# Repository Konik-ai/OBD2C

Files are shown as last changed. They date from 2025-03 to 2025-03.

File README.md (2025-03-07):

Designed using Kicad 8

Unlike harness box, OBD2-C doesn't use the relay. 

The purpose of it is to sniff CAN buses that are already present in OBD-2 port, similar to what white panda was doing in the past, but compatible with [OBD-C](https://github.com/commaai/neo/blob/master/car_harness/OBD-C.sch.pdf), though often only diagnostic CAN is populated on OBD-2.

The device exposes three CAN buses out of OBD-C:
- CAN0 (3, 11)
- CAN1 is routed to the JST (pin 2,3) connector (can be connected .e.g to [StepperServoCAN](https://github.com/dzid26/StepperServo-hardware)) and has optional 120ohm termination resistor (see jumpers).
Alternatively, bus 1 can be rerouted using jumpers as a GMLAN (obd pin 1) as in [white panda](https://comma-ai.medium.com/a-panda-and-a-cabana-how-to-get-started-car-hacking-with-comma-ai-b5e46fae8646) - but unlike [white panda](https://github.com/martiinezz/panda/blob/master/white-hw/README.md) it uses single wire [hack](https://canhacker.com/examples/gm-lan-single-wire-can-examples/) and is not tested
- CAN2 (pins 12, 13)
- CAN3 (pins 6, 14) - this one can be used e.g. as "[ELM327](https://github.com/commaai/panda/blob/master/examples/query_vin_and_stats.py)" or [vin](https://github.com/commaai/openpilot/blob/master/selfdrive/debug/car/vin.py) reading in openpilot 


As seen from PCB side

Some notes regarding openpilot bus names mapping to STM32 peripherals and [harness](https://github.com/commaai/neo/blob/master/car_harness/v1/open_pinout.sch.pdf) - (the indexes are not always consistent):
`HARNESS_STATUS_NORMAL`
| openpilot | STM32F4 | Harness |  WhitePanda 
| ---|---|---|---|
|sbu1| | sbu2|  |
|sbu2| | sbu1|  |
| bus 0  | CAN1 |  CAN0  | CAN1|
| bus 1  | CAN2 |  CAN1  | CAN2 |
|bus 1(obd)| CAN2 alt| CAN3| GMLAN|
| bus 2  | CAN3 | CAN2 | CAN3|

`HARNESS_STATUS_FLIPPED`
| openpilot | STM32F4 | Harness |  WhitePanda 
| ---|---|---|---|
|sbu1| | sbu1|  |
|sbu2| | sbu2|  |
| bus 0  | CAN3 |  CAN0  | CAN1|
| bus 1  | CAN2 alt|  CAN1  | CAN2 |
|bus 1(obd)| CAN2 | CAN3 | GMLAN|
| bus 2  | CAN1 | CAN2 | CAN3|

`+obd` means `set_obd_multiplexing(True)` in openpilot aka `panda.set_obd(True)` in panda lib aka `set_can_mode(CAN_MODE_OBD_CAN2)` in panda firmware.

Confusing? Yes. 
Especially inside panda [firmware](https://github.com/commaai/panda/pull/1860).

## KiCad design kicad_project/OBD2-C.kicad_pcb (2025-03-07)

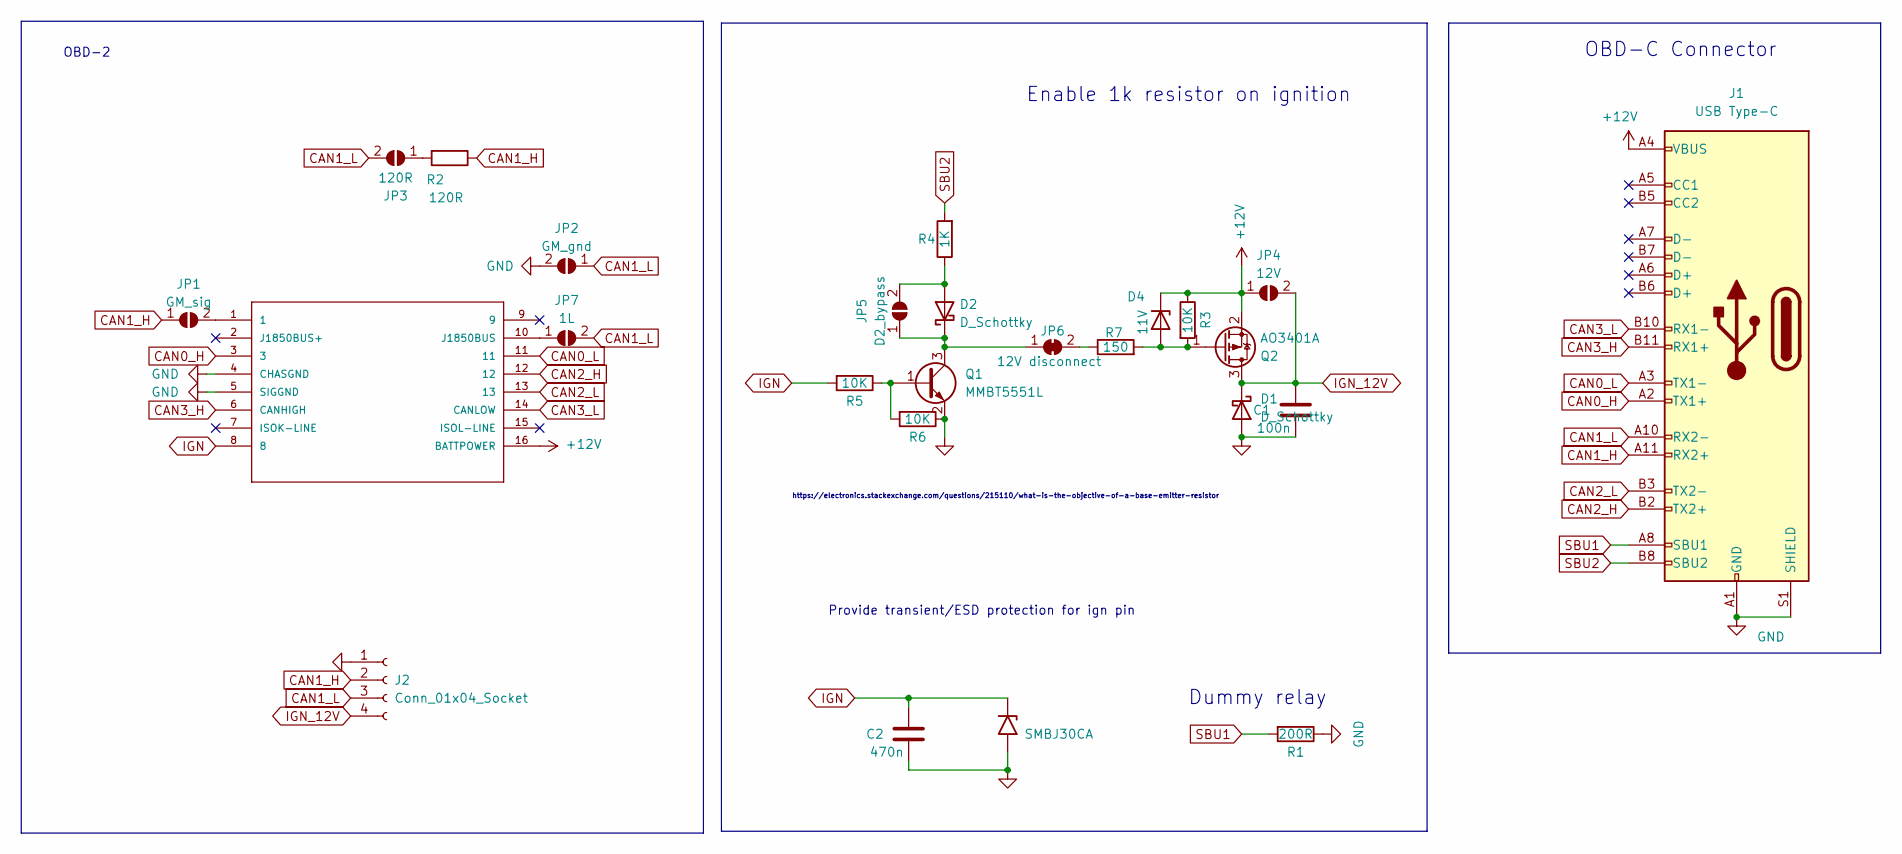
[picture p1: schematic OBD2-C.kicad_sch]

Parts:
C1: 100n; C_0603_1608Metric; Part CL21B474KBFNNNE; LCSC C14663
C2: 470n; C_0805_2012Metric; Part CL21B474KBFNNNE; LCSC C13967
D1, D2: D_Schottky; D_SOD-323; LCSC C64886
D3: SMBJ30CA; D_SOD-123F; LCSC C2990493
D4: 11V; D_SOD-123; LCSC C2932743
J1: USB Type-C; USB_C_Receptacle_GCT_USB4115-03-C; LCSC C2689742
J2: Conn_01x04_Socket; LCSC C566013
JP1: GM_sig; SolderJumper-2_P1.3mm_Open_TrianglePad1.0x1.5mm
JP2: GM_gnd; SolderJumper-2_P1.3mm_Open_TrianglePad1.0x1.5mm
JP3: 120R; SolderJumper-2_P1.3mm_Open_TrianglePad1.0x1.5mm
JP4: 12V; SolderJumper-2_P1.3mm_Open_TrianglePad1.0x1.5mm
JP5: D2_bypass; SolderJumper-2_P1.3mm_Open_RoundedPad1.0x1.5mm
JP6: 12V disconnect; SolderJumper-2_P1.3mm_Bridged_RoundedPad1.0x1.5mm
JP7: 1L; SolderJumper-2_P1.3mm_Open_TrianglePad1.0x1.5mm
M1: OBDII
Q1: MMBT5551L; SOT-23; LCSC C2145
Q2: AO3401A; SOT-23; LCSC C15127
R1: 200R; R_0805_2012Metric; LCSC C17540
R2: 120R; R_1206_3216Metric_Pad1.30x1.75mm_HandSolder; LCSC C17909
R3, R5, R6: 10K; R_0402_1005Metric; LCSC C25744
R4: 1K; R_0603_1608Metric; LCSC C21190
R7: 150; R_0603_1608Metric; LCSC C22808

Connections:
+12V: D4.1 (K), J1.A4 (VBUS), J1.A9 (VBUS), J1.B4 (VBUS), J1.B9 (VBUS), JP4.1 (A), M1.16 (BATTPOWER), Q2.2 (S), R3.1
CAN0_H: J1.A2 (TX1+), M1.3
CAN0_L: J1.A3 (TX1-), M1.11
CAN1_H: J1.A11 (RX2+), J2.2, JP1.1 (A), R2.1
CAN1_L: J1.A10 (RX2-), J2.3, JP2.1 (A), JP3.2 (B), JP7.2 (B)
CAN2_H: J1.B2 (TX2+), M1.12
CAN2_L: J1.B3 (TX2-), M1.13
CAN3_H: J1.B11 (RX1+), M1.6 (CANHIGH)
CAN3_L: J1.B10 (RX1-), M1.14 (CANLOW)
GND: C1.2, C2.2, D1.2 (A), D3.2 (A2), J1.A1 (GND), J1.A12 (GND), J1.B1 (GND), J1.B12 (GND), J1.S1 (SHIELD), J2.1, JP2.2 (B), M1.4 (CHASGND), M1.5 (SIGGND), Q1.2 (E), R1.1, R6.1
IGN: C2.1, D3.1 (A1), M1.8, R5.2
IGN_12V: C1.1, D1.1 (K), J2.4, JP4.2 (B), Q2.3 (D)
unnamed: D2.2 (A), JP5.2 (B), R4.1
unnamed: D2.1 (K), JP5.1 (A), JP6.1 (A), Q1.3 (C)
unnamed: D4.2 (A), Q2.1 (G), R3.2, R7.2
unnamed: JP1.2 (B), M1.1
unnamed: JP3.1 (A), R2.2
unnamed: JP6.2 (B), R7.1
unnamed: JP7.1 (A), M1.10 (J1850BUS)
unnamed: Q1.1 (B), R5.1, R6.2
SBU1: J1.A8 (SBU1), R1.2
SBU2: J1.B8 (SBU2), R4.2

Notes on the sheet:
OBD-2
OBD-C Connector
https://electronics.stackexchange.com/questions/215110/what-is-the-objective-of-a-base-emitter-resistor
Dummy relay
Enable 1k resistor on ignition
Provide transient/ESD protection for ign pin

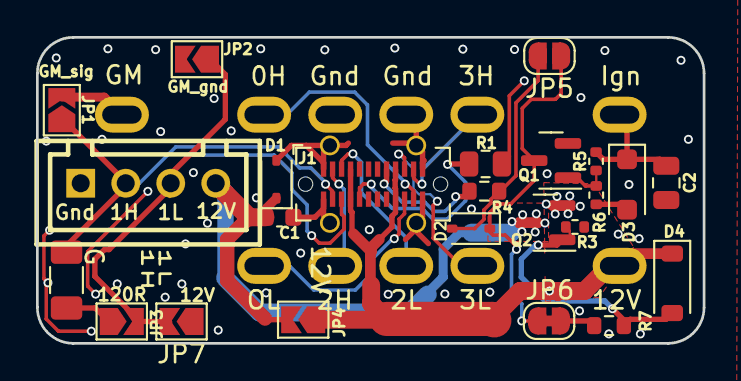
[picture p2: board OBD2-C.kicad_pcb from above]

Board: 2 copper layers, 37.0 x 17.0 mm, 25 parts (1 on the bottom side), 21 nets.
